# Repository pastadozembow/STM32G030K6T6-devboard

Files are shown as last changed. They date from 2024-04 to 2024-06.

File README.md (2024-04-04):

This board was designed to be as cheap as possible while remaining fast and flexible to use. It can be powered by a 12v source via the vin pin, It has a 64mhz 32bit ARM MCU and can be flashed via an USB port which is connected to an USB to UART converter.
5 boards assembled by hand cost 20$(converted from PLN so it can be cheaper depending on your component source and country)
If you have any issues or ideas for improvments DM me on discord: lorbasta

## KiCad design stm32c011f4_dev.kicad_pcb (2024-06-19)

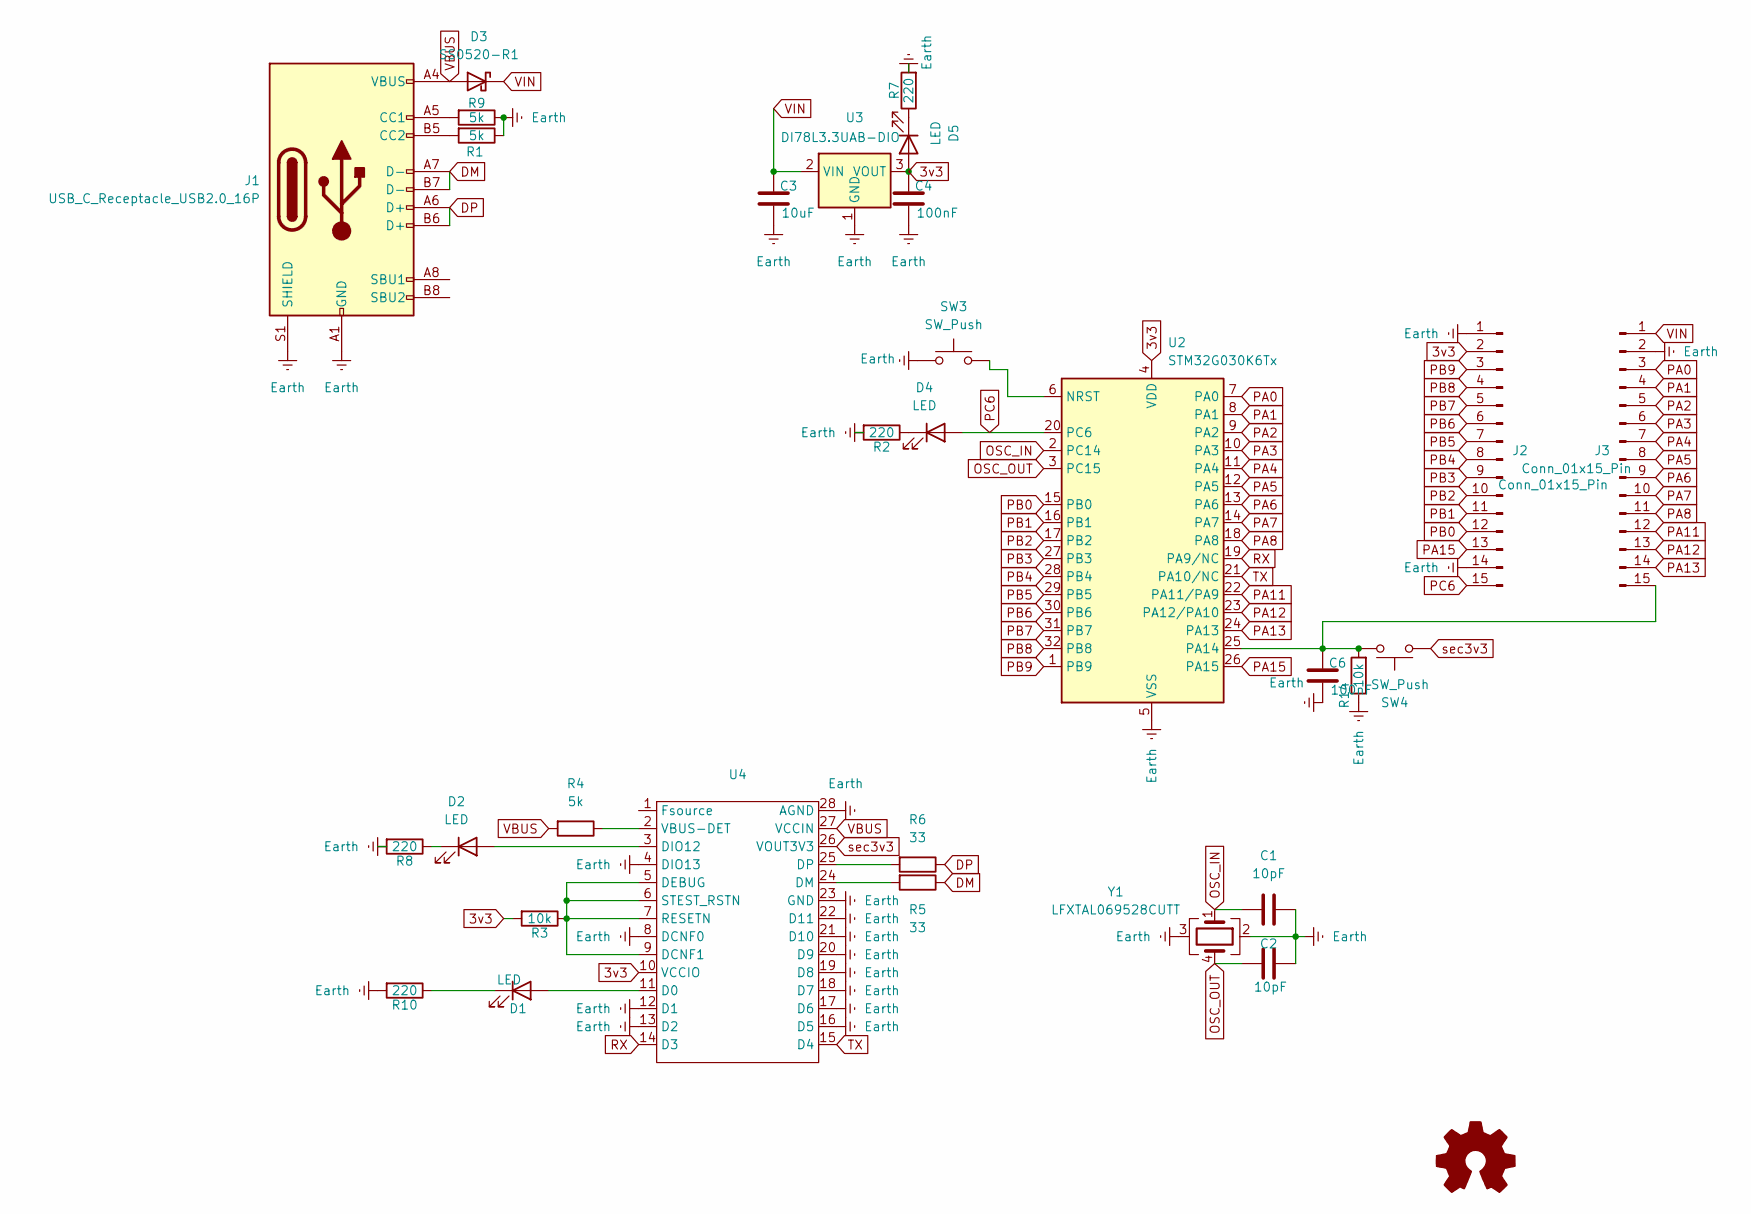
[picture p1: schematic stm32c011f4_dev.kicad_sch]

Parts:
C1, C2: 10pF; C_0603_1608Metric
C3: 10uF; C_1206_3216Metric
C4, C6: 100nF; C_0603_1608Metric
D1, D2, D4, D5: LED; LED_0603_1608Metric
D3: SS0520-R1; D_SOD-123
J1: USB_C_Receptacle_USB2.0_16P; USB_C_Receptacle_GCT_USB4085
J2, J3: Conn_01x15_Pin; PinHeader_1x15_P2.54mm_Vertical
R1, R4, R9: 5k; R_0603_1608Metric
R2, R7, R8, R10: 220; R_0603_1608Metric
R3, R14: 10k; R_0603_1608Metric
R5, R6: 33; R_0603_1608Metric
SW3, SW4: SW_Push; SW_SPST_EVQQ2
U2: STM32G030K6Tx; LQFP-32_7x7mm_P0.8mm
U3: DI78L3.3UAB-DIO; SOT-89-3
U4: FT260S-U
Y1: LFXTAL069528CUTT; Crystal_SMD_2016-4Pin_2.0x1.6mm

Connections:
3v3: C4.1, D5.2 (A), J2.2, R3.2, U2.4 (VDD), U3.3 (VOUT), U4.10 (VCCIO)
DM: J1.A7 (D-), J1.B7 (D-), R5.1
DP: J1.A6 (D+), J1.B6 (D+), R6.1
Earth: C1.2, C2.2, C3.2, C4.2, C6.2, J1.A1 (GND), J1.A12 (GND), J1.B1 (GND), J1.B12 (GND), J1.S1 (SHIELD), J2.1, J2.14, J3.2, R1.1, R2.2, R7.2, R8.2, R9.1, R10.2, R14.1, SW3.1, U2.5 (VSS), U3.1 (GND), U4.4 (DIO13), U4.8 (DCNF0), U4.12 (D1), U4.13 (D2), U4.16 (D5), U4.17 (D6), U4.18 (D7), U4.19 (D8), U4.20 (D9), U4.21 (D10), U4.22 (D11), U4.23 (GND), U4.28 (AGND), Y1.2, Y1.3
unnamed: D1.2 (A), U4.11 (D0)
unnamed: D1.1 (K), R10.1
unnamed: D2.2 (A), U4.3 (DIO12)
unnamed: D2.1 (K), R8.1
unnamed: D4.1 (K), R2.1
unnamed: D5.1 (K), R7.1
unnamed: J1.A5 (CC1), R9.2
unnamed: J1.B5 (CC2), R1.2
unnamed: C6.1, J3.15, R14.2, SW4.1, U2.25 (PA14)
unnamed: SW3.2, U2.6 (NRST)
unnamed: R3.1, U4.5 (DEBUG), U4.6 (STEST_RSTN), U4.7 (RESETN), U4.9 (DCNF1)
unnamed: R5.2, U4.24 (DM)
unnamed: R6.2, U4.25 (DP)
unnamed: R4.1, U4.2 (VBUS-DET)
OSC_IN: C1.1, U2.2 (PC14), Y1.1
OSC_OUT: C2.1, U2.3 (PC15), Y1.4
PA0: J3.3, U2.7 (PA0)
PA1: J3.4, U2.8 (PA1)
PA2: J3.5, U2.9 (PA2)
PA3: J3.6, U2.10 (PA3)
PA4: J3.7, U2.11 (PA4)
PA5: J3.8, U2.12 (PA5)
PA6: J3.9, U2.13 (PA6)
PA7: J3.10, U2.14 (PA7)
PA8: J3.11, U2.18 (PA8)
PA11: J3.12, U2.22 (PA11/PA9)
PA12: J3.13, U2.23 (PA12/PA10)
PA13: J3.14, U2.24 (PA13)
PA15: J2.13, U2.26 (PA15)
PB0: J2.12, U2.15 (PB0)
PB1: J2.11, U2.16 (PB1)
PB2: J2.10, U2.17 (PB2)
PB3: J2.9, U2.27 (PB3)
PB4: J2.8, U2.28 (PB4)
PB5: J2.7, U2.29 (PB5)
PB6: J2.6, U2.30 (PB6)
PB7: J2.5, U2.31 (PB7)
PB8: J2.4, U2.32 (PB8)
PB9: J2.3, U2.1 (PB9)
PC6: D4.2 (A), J2.15, U2.20 (PC6)
RX: U2.19 (PA9/NC), U4.14 (D3)
TX: U2.21 (PA10/NC), U4.15 (D4)
VBUS: D3.2 (A), J1.A4 (VBUS), J1.A9 (VBUS), J1.B4 (VBUS), J1.B9 (VBUS), R4.2, U4.27 (VCCIN)
VIN: C3.1, D3.1 (K), J3.1, U3.2 (VIN)
sec3v3: SW4.2, U4.26 (VOUT3V3)

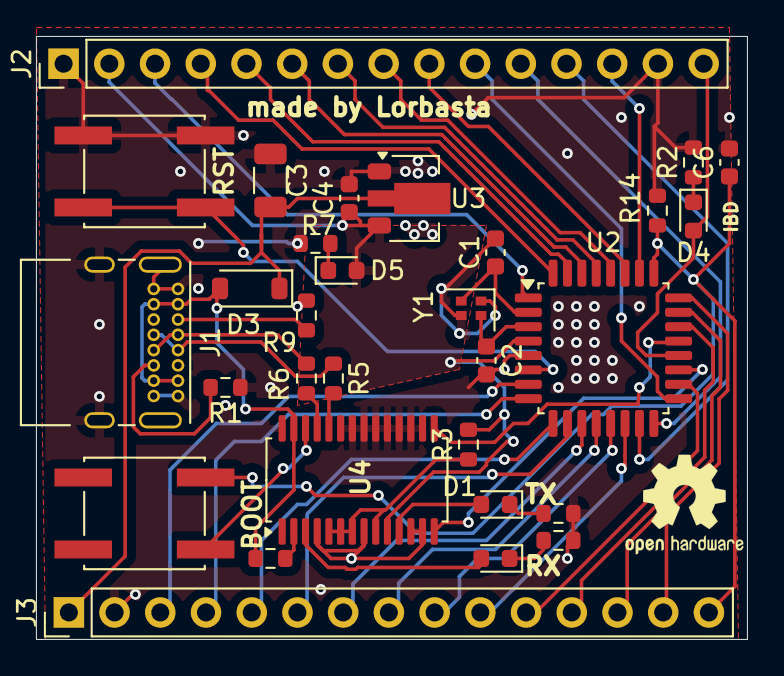
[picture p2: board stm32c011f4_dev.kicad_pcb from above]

Board: 2 copper layers, 39.5 x 33.5 mm, 30 parts (0 on the bottom side), 49 nets.

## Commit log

2024-04-03 PCB and schematic on KiCAD
    [stm32c011f4_dev.kicad_pcb, stm32c011f4_dev.kicad_sch]
2024-04-03 KiCAD project
    [stm32c011f4_dev.kicad_pcb, stm32c011f4_dev.kicad_sch]
2024-04-03 Gerber file
2024-04-03 Gerber and pcb update
2024-04-03 pcb update
2024-04-04 Silkscreen update
    [stm32c011f4_dev.kicad_pcb]
2024-04-05 pcb update
    fixed gnd mistakes
    [stm32c011f4_dev.kicad_pcb]
2024-04-09 PCB update
    adding swd and improving traces
    [stm32c011f4_dev.kicad_pcb, stm32c011f4_dev.kicad_sch]
2024-05-28 Changing usb-c from smt to tht
    [stm32c011f4_dev.kicad_pcb, stm32c011f4_dev.kicad_sch]
2024-06-19 tht usb and one resistor per led cathode
    :333
    [stm32c011f4_dev.kicad_pcb, stm32c011f4_dev.kicad_sch]
2024-06-19 tht usb and one resistor per cathode
    :33333
